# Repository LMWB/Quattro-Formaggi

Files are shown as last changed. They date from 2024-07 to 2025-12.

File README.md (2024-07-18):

# DS18B20_OneWire
One Wire Temperature Sensor Breakout Board on Arduino Shield Format and STM32 Nucleo-F446 Based Software

# Features
- four channels 1-Wire Interface with onboard driver stage 
- designed for DS18B20 Temperature Sensor but any 1-Wire Sensor / Actor would do (minor software adjustments required)
- Industrial ready CAN-Bus interface
    - works with standard (11-Bit) and extended (29-Bit) CAN identifier
- Industrial ready Modbus interface will come soon
- Arduino-Shield layout will fit on several Dev-Boards including all Nucleo-64 boards and Arduino-UNO boards

The 1-Wire Search Algorithm and Driver Stage are basically taken from MAXIM Datasheet and Microship App-Notes.

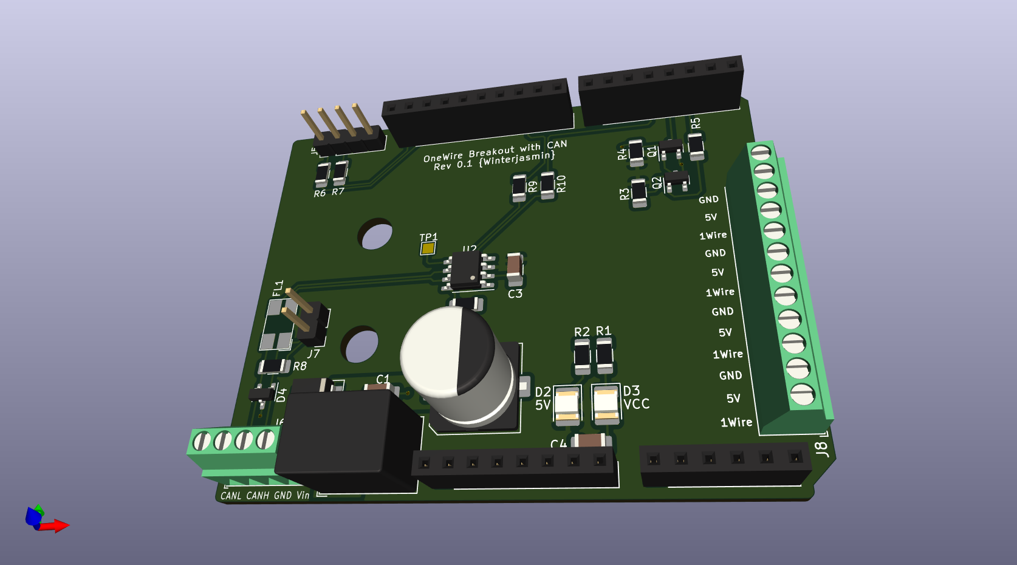
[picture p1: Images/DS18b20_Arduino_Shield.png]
1Wire Arduino Shield

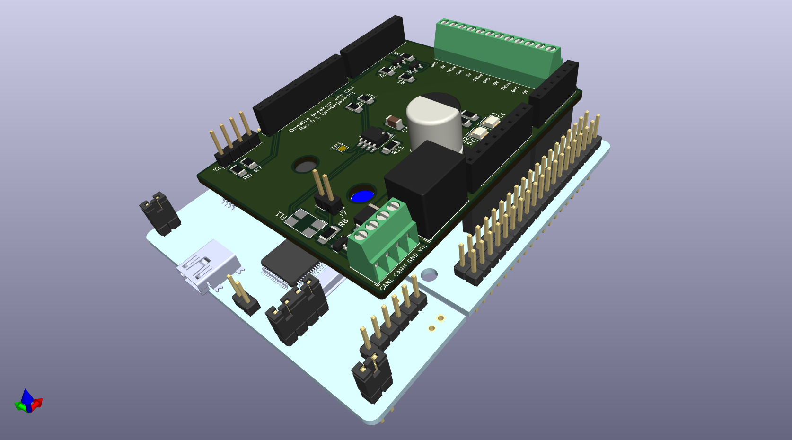
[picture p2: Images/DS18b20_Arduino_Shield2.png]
1Wire Arduino Shield with Nucleo

Schematics

To study some of my testing done so far please have a look [here](/Testing/README.md).

# Quattro Formaggi vs. Quattro Stagioni

# ToDo
- add User-LED on Arduino Shield (Nucleo LED is covered) [HW]
- add Temperature Results to CAN Message [SW]
- use bigger terminal blocks for 1-Wire Interface [HW]
- use bigger terminal blocks for Power Supply and CAN [HW]

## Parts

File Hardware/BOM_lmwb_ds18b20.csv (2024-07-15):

Source: | /home/lukas/KiCad/lmwb_ds18b20/lmwb_ds18b20.kicad_sch
Date: | Sat 03 Feb 2024 16:29:55 CET
Tool: | Eeschema 6.0.11-2627ca5db0~126~ubuntu22.04.1
Generator: | /usr/share/kicad/plugins/bom_csv_grouped_by_value_with_fp.py
Component Count: | 33
Ref | Qnty | Value | Cmp name | Footprint | Description | Vendor
C1, C3, C4, | 3 | 100n | C | Capacitor_SMD:C_1206_3216Metric_Pad1.33x1.80mm_HandSolder | Unpolarized capacitor
C2, | 1 | 47u | C_Polarized | Capacitor_SMD:CP_Elec_10x12.5 | Polarized capacitor
D1, | 1 | US1D | US1D | Diode_SMD:D_SMA | 200V, 1A, General Purpose Rectifier Diode, SMA(DO-214AC)
D2, D3, | 2 | LED_YE | LED | LED_SMD:LED_1210_3225Metric_Pad1.42x2.65mm_HandSolder | Light emitting diode
D4, | 1 | SP0502BAHT | SP0502BAHT | Package_TO_SOT_SMD:SOT-23 | TVS Diode Array, 5.5V Standoff, 2 Channels, SOT-23 package
FL1, | 1 | WE_LineFilter_CAN | WE_LineFilter_CAN | CommonUsedElemetsLMWB:L_CommonModeChoke_CAN_lmwb | EMI 2-inductor filter, pin-connections 1-4 and 2-3
J1, | 1 | Power | Conn_01x08 | Connector_PinSocket_2.54mm:PinSocket_1x08_P2.54mm_Vertical | Generic connector, single row, 01x08, script generated (kicad-library-utils/schlib/autogen/connector/)
J2, | 1 | Digital/PWM | Conn_01x10 | Connector_PinSocket_2.54mm:PinSocket_1x10_P2.54mm_Vertical | Generic connector, single row, 01x10, script generated (kicad-library-utils/schlib/autogen/connector/)
J3, | 1 | Analog | Conn_01x06 | Connector_PinSocket_2.54mm:PinSocket_1x06_P2.54mm_Vertical | Generic connector, single row, 01x06, script generated (kicad-library-utils/schlib/autogen/connector/)
J4, | 1 | Digital/PWM | Conn_01x08 | Connector_PinSocket_2.54mm:PinSocket_1x08_P2.54mm_Vertical | Generic connector, single row, 01x08, script generated (kicad-library-utils/schlib/autogen/connector/)
J5, | 1 | Conn_01x04 | Conn_01x04 | Connector_PinHeader_2.54mm:PinHeader_1x04_P2.54mm_Vertical | Generic connector, single row, 01x04, script generated (kicad-library-utils/schlib/autogen/connector/)
J6, | 1 | Conn_01x04 | Conn_01x04 | TerminalBlock_Phoenix:TerminalBlock_Phoenix_MPT-0,5-4-2.54_1x04_P2.54mm_Horizontal | Generic connector, single row, 01x04, script generated (kicad-library-utils/schlib/autogen/connector/)
J7, | 1 | Conn_01x02_Male | Conn_01x02_Male | Connector_PinHeader_2.54mm:PinHeader_1x02_P2.54mm_Vertical | Generic connector, single row, 01x02, script generated (kicad-library-utils/schlib/autogen/connector/)
J8, | 1 | Conn_01x12 | Conn_01x12 | TerminalBlock_Phoenix:TerminalBlock_Phoenix_MPT-0,5-12-2.54_1x12_P2.54mm_Horizontal | Generic connector, single row, 01x12, script generated (kicad-library-utils/schlib/autogen/connector/)
Q1, Q2, | 2 | BC847 | BC847 | Package_TO_SOT_SMD:SOT-23 | 0.1A Ic, 45V Vce, NPN Transistor, SOT-23
R1, R5, | 2 | 10k | R | Resistor_SMD:R_1206_3216Metric_Pad1.30x1.75mm_HandSolder | Resistor
R2, | 1 | 3k3 | R | Resistor_SMD:R_1206_3216Metric_Pad1.30x1.75mm_HandSolder | Resistor
R3, | 1 | 4k7 | R | Resistor_SMD:R_1206_3216Metric_Pad1.30x1.75mm_HandSolder | Resistor
R4, | 1 | 100k | R | Resistor_SMD:R_1206_3216Metric_Pad1.30x1.75mm_HandSolder | Resistor
R6, R7, | 2 | 47 | R | Resistor_SMD:R_1206_3216Metric_Pad1.30x1.75mm_HandSolder | Resistor
R8, | 1 | 120 | R | Resistor_SMD:R_1206_3216Metric_Pad1.30x1.75mm_HandSolder | Resistor
R9, R10, | 2 | 0 | R | Resistor_SMD:R_1206_3216Metric_Pad1.30x1.75mm_HandSolder | Resistor
R11, | 1 | 22k | R | Resistor_SMD:R_1206_3216Metric_Pad1.30x1.75mm_HandSolder | Resistor
TP1, | 1 | TestPoint_Probe | TestPoint_Probe | TestPoint:TestPoint_Pad_1.5x1.5mm | test point (alternative probe-style design)
U1, | 1 | R-78E9.0-0.5 | R-78E9.0-0.5 | Converter_DCDC:Converter_DCDC_RECOM_R-78E-0.5_THT | 500mA Step-Down DC/DC-Regulator, 12-28V input, 9V fixed Output Voltage, LM78xx replacement, -40°C to +85°C, SIP3
U2, | 1 | MCP2551-I-SN | MCP2551-I-SN | Package_SO:SOIC-8_3.9x4.9mm_P1.27mm | High-Speed CAN Transceiver, 1Mbps, 5V supply, SOIC-8

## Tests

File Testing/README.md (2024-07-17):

# Testing
Because of lacking a proper CAN-Testing-Tool like this [PCAN-USB](https://www.peak-system.com/PCAN-USB.199.0.html?&L=1) I just used a Arduino with CAN-Shield and a minimal Arduino Sketch.
The Arduino program sends periodic test messages and receives CAN-messages from the Nucleo Board. With this I could ensure CAN (especially the CAN transceiver IC) works both directions.

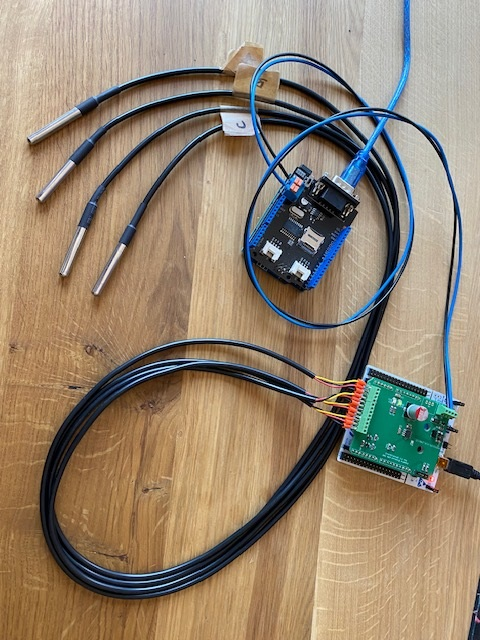
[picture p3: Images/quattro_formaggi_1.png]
arrangement Arduino and Nucleo


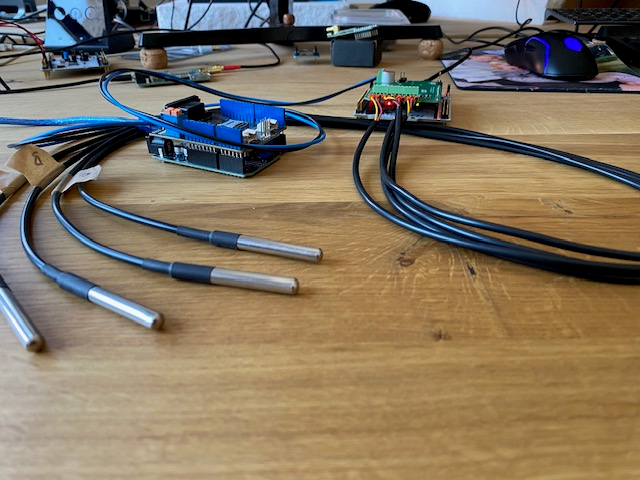
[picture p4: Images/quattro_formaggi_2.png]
arrangement Arduino and Nucleo 2


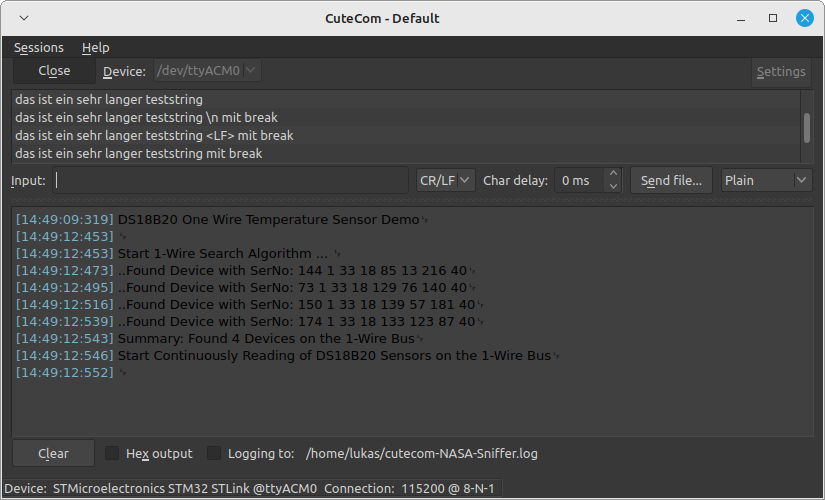
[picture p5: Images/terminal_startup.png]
terminal startup message


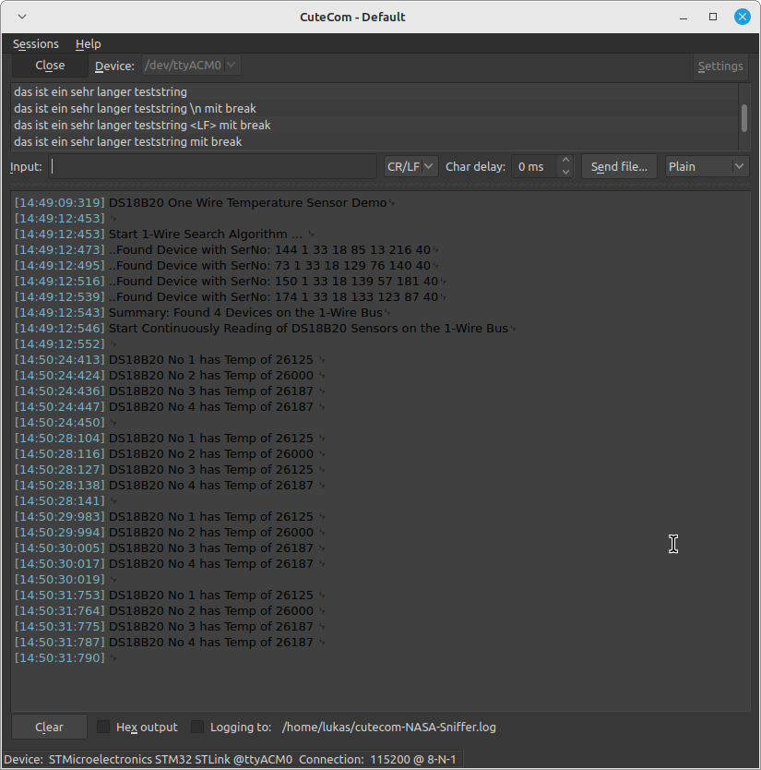
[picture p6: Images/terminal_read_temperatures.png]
terminal search and read DS18B20 sensors


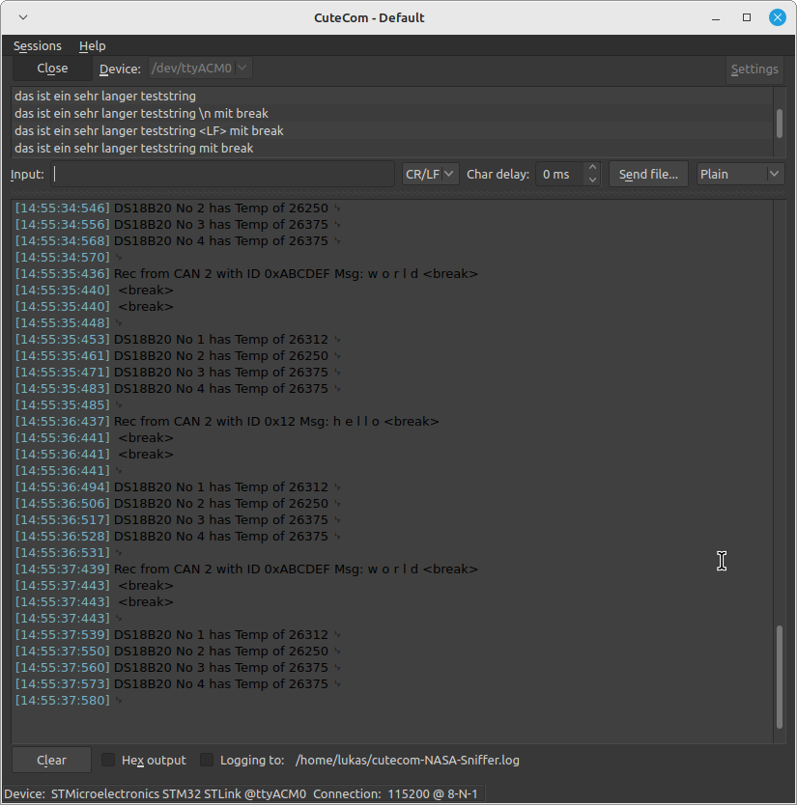
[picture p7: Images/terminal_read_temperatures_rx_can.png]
terminal send and receive CAN messages


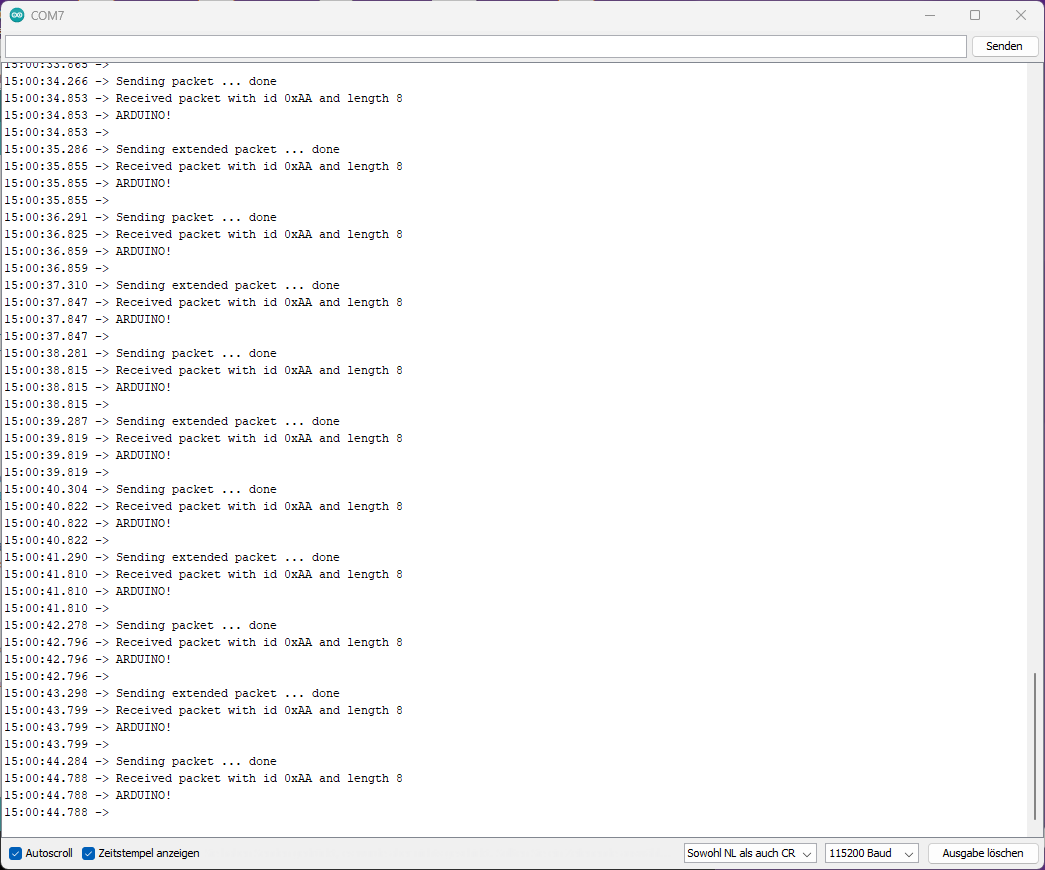
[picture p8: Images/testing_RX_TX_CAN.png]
Arduino terminal send and receive CAN messages


## Hardware
todo

## Software
todo

## CAN-Bus
todo

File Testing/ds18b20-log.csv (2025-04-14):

tick | 5000 | DS18B20_1 | -2500 | GradC | DS18B20_2 | 68000 | GradC | DS18B20_3 | 20875 | GradC | DS18B20_4 | 21062 | GradC
tick | 10000 | DS18B20_1 | -2500 | GradC | DS18B20_2 | 68000 | GradC | DS18B20_3 | 20875 | GradC | DS18B20_4 | 21062 | GradC
tick | 15000 | DS18B20_1 | -2500 | GradC | DS18B20_2 | 67937 | GradC | DS18B20_3 | 20937 | GradC | DS18B20_4 | 21062 | GradC
tick | 20000 | DS18B20_1 | -2500 | GradC | DS18B20_2 | 67875 | GradC | DS18B20_3 | 20875 | GradC | DS18B20_4 | 21062 | GradC
tick | 25000 | DS18B20_1 | -2500 | GradC | DS18B20_2 | 67812 | GradC | DS18B20_3 | 20937 | GradC | DS18B20_4 | 21125 | GradC
tick | 30000 | DS18B20_1 | -2500 | GradC | DS18B20_2 | 67812 | GradC | DS18B20_3 | 20937 | GradC | DS18B20_4 | 21125 | GradC
tick | 35000 | DS18B20_1 | -2500 | GradC | DS18B20_2 | 67750 | GradC | DS18B20_3 | 20937 | GradC | DS18B20_4 | 21125 | GradC
tick | 40000 | DS18B20_1 | -2562 | GradC | DS18B20_2 | 67687 | GradC | DS18B20_3 | 20937 | GradC | DS18B20_4 | 21125 | GradC
tick | 45032 | DS18B20_1 | -2562 | GradC | DS18B20_2 | 67625 | GradC | DS18B20_3 | 20937 | GradC | DS18B20_4 | 21125 | GradC
tick | 50032 | DS18B20_1 | -2562 | GradC | DS18B20_2 | 67625 | GradC | DS18B20_3 | 20937 | GradC | DS18B20_4 | 21125 | GradC
tick | 55032 | DS18B20_1 | -2562 | GradC | DS18B20_2 | 67562 | GradC | DS18B20_3 | 20937 | GradC | DS18B20_4 | 21125 | GradC
tick | 60032 | DS18B20_1 | -2562 | GradC | DS18B20_2 | 67500 | GradC | DS18B20_3 | 20937 | GradC | DS18B20_4 | 21125 | GradC
tick | 65032 | DS18B20_1 | -2562 | GradC | DS18B20_2 | 67437 | GradC | DS18B20_3 | 20937 | GradC | DS18B20_4 | 21125 | GradC
tick | 70032 | DS18B20_1 | -2562 | GradC | DS18B20_2 | 67375 | GradC | DS18B20_3 | 20937 | GradC | DS18B20_4 | 21125 | GradC
tick | 75032 | DS18B20_1 | -2562 | GradC | DS18B20_2 | 67312 | GradC | DS18B20_3 | 20937 | GradC | DS18B20_4 | 21125 | GradC
tick | 80032 | DS18B20_1 | -2562 | GradC | DS18B20_2 | 67250 | GradC | DS18B20_3 | 20937 | GradC | DS18B20_4 | 21125 | GradC
tick | 85032 | DS18B20_1 | -2562 | GradC | DS18B20_2 | 67250 | GradC | DS18B20_3 | 20937 | GradC | DS18B20_4 | 21125 | GradC
tick | 90032 | DS18B20_1 | -2625 | GradC | DS18B20_2 | 67187 | GradC | DS18B20_3 | 20937 | GradC | DS18B20_4 | 21125 | GradC
tick | 95032 | DS18B20_1 | -2625 | GradC | DS18B20_2 | 67062 | GradC | DS18B20_3 | 20937 | GradC | DS18B20_4 | 21187 | GradC
tick | 100032 | DS18B20_1 | -2625 | GradC | DS18B20_2 | 67062 | GradC | DS18B20_3 | 21000 | GradC | DS18B20_4 | 21187 | GradC
tick | 105032 | DS18B20_1 | -2625 | GradC | DS18B20_2 | 67000 | GradC | DS18B20_3 | 21000 | GradC | DS18B20_4 | 21187 | GradC
tick | 110032 | DS18B20_1 | -2625 | GradC | DS18B20_2 | 66937 | GradC | DS18B20_3 | 21000 | GradC | DS18B20_4 | 21187 | GradC
tick | 115032 | DS18B20_1 | -2625 | GradC | DS18B20_2 | 66875 | GradC | DS18B20_3 | 21000 | GradC | DS18B20_4 | 21187 | GradC
tick | 120032 | DS18B20_1 | -2687 | GradC | DS18B20_2 | 66812 | GradC | DS18B20_3 | 21000 | GradC | DS18B20_4 | 21187 | GradC
tick | 125032 | DS18B20_1 | -2687 | GradC | DS18B20_2 | 66750 | GradC | DS18B20_3 | 21000 | GradC | DS18B20_4 | 21187 | GradC
tick | 130032 | DS18B20_1 | -2687 | GradC | DS18B20_2 | 66687 | GradC | DS18B20_3 | 21000 | GradC | DS18B20_4 | 21187 | GradC
tick | 135032 | DS18B20_1 | -2687 | GradC | DS18B20_2 | 66687 | GradC | DS18B20_3 | 21000 | GradC | DS18B20_4 | 21187 | GradC
tick | 140032 | DS18B20_1 | -2687 | GradC | DS18B20_2 | 66562 | GradC | DS18B20_3 | 21000 | GradC | DS18B20_4 | 21187 | GradC
tick | 145032 | DS18B20_1 | -2687 | GradC | DS18B20_2 | 66562 | GradC | DS18B20_3 | 21000 | GradC | DS18B20_4 | 21187 | GradC
tick | 150032 | DS18B20_1 | -2750 | GradC | DS18B20_2 | 66500 | GradC | DS18B20_3 | 21000 | GradC | DS18B20_4 | 21187 | GradC
tick | 155032 | DS18B20_1 | -2750 | GradC | DS18B20_2 | 66437 | GradC | DS18B20_3 | 21000 | GradC | DS18B20_4 | 21187 | GradC
tick | 160044 | DS18B20_1 | -2750 | GradC | DS18B20_2 | 66375 | GradC | DS18B20_3 | 21000 | GradC | DS18B20_4 | 21187 | GradC
tick | 165044 | DS18B20_1 | -2750 | GradC | DS18B20_2 | 66312 | GradC | DS18B20_3 | 21000 | GradC | DS18B20_4 | 21187 | GradC
tick | 170044 | DS18B20_1 | -2750 | GradC | DS18B20_2 | 66250 | GradC | DS18B20_3 | 21000 | GradC | DS18B20_4 | 21187 | GradC
tick | 175044 | DS18B20_1 | -2750 | GradC | DS18B20_2 | 66187 | GradC | DS18B20_3 | 21000 | GradC | DS18B20_4 | 21187 | GradC
tick | 180074 | DS18B20_1 | -2750 | GradC | DS18B20_2 | 66125 | GradC | DS18B20_3 | 21000 | GradC | DS18B20_4 | 21187 | GradC
tick | 185074 | DS18B20_1 | -2812 | GradC | DS18B20_2 | 66125 | GradC | DS18B20_3 | 21000 | GradC | DS18B20_4 | 21187 | GradC
tick | 190074 | DS18B20_1 | -2812 | GradC | DS18B20_2 | 66062 | GradC | DS18B20_3 | 21000 | GradC | DS18B20_4 | 21187 | GradC
tick | 195074 | DS18B20_1 | -2812 | GradC | DS18B20_2 | 66000 | GradC | DS18B20_3 | 21000 | GradC | DS18B20_4 | 21187 | GradC
tick | 200101 | DS18B20_1 | -2812 | GradC | DS18B20_2 | 65937 | GradC | DS18B20_3 | 21000 | GradC | DS18B20_4 | 21187 | GradC
tick | 205101 | DS18B20_1 | -2812 | GradC | DS18B20_2 | 65875 | GradC | DS18B20_3 | 21000 | GradC | DS18B20_4 | 21187 | GradC
tick | 210101 | DS18B20_1 | -2812 | GradC | DS18B20_2 | 65812 | GradC | DS18B20_3 | 21000 | GradC | DS18B20_4 | 21187 | GradC
tick | 215101 | DS18B20_1 | -2812 | GradC | DS18B20_2 | 65687 | GradC | DS18B20_3 | 21000 | GradC | DS18B20_4 | 21187 | GradC
tick | 220127 | DS18B20_1 | -2875 | GradC | DS18B20_2 | 65625 | GradC | DS18B20_3 | 21000 | GradC | DS18B20_4 | 21187 | GradC
tick | 225127 | DS18B20_1 | -2875 | GradC | DS18B20_2 | 65625 | GradC | DS18B20_3 | 21000 | GradC | DS18B20_4 | 21187 | GradC
tick | 230127 | DS18B20_1 | -2875 | GradC | DS18B20_2 | 65562 | GradC | DS18B20_3 | 21000 | GradC | DS18B20_4 | 21187 | GradC
tick | 235127 | DS18B20_1 | -2875 | GradC | DS18B20_2 | 65500 | GradC | DS18B20_3 | 21000 | GradC | DS18B20_4 | 21187 | GradC
tick | 240156 | DS18B20_1 | -2875 | GradC | DS18B20_2 | 65437 | GradC | DS18B20_3 | 21000 | GradC | DS18B20_4 | 21187 | GradC
tick | 245156 | DS18B20_1 | -2875 | GradC | DS18B20_2 | 65375 | GradC | DS18B20_3 | 21000 | GradC | DS18B20_4 | 21250 | GradC
tick | 250156 | DS18B20_1 | -2875 | GradC | DS18B20_2 | 65312 | GradC | DS18B20_3 | 21000 | GradC | DS18B20_4 | 21187 | GradC
tick | 255156 | DS18B20_1 | -2875 | GradC | DS18B20_2 | 65250 | GradC | DS18B20_3 | 21000 | GradC | DS18B20_4 | 21187 | GradC
tick | 260188 | DS18B20_1 | -2937 | GradC | DS18B20_2 | 65187 | GradC | DS18B20_3 | 21000 | GradC | DS18B20_4 | 21250 | GradC
tick | 265188 | DS18B20_1 | -2937 | GradC | DS18B20_2 | 65125 | GradC | DS18B20_3 | 21000 | GradC | DS18B20_4 | 21187 | GradC
tick | 270188 | DS18B20_1 | -2937 | GradC | DS18B20_2 | 65062 | GradC | DS18B20_3 | 21000 | GradC | DS18B20_4 | 21187 | GradC
tick | 275188 | DS18B20_1 | -2937 | GradC | DS18B20_2 | 65000 | GradC | DS18B20_3 | 21000 | GradC | DS18B20_4 | 21250 | GradC
tick | 280222 | DS18B20_1 | -2937 | GradC | DS18B20_2 | 64937 | GradC | DS18B20_3 | 21000 | GradC | DS18B20_4 | 21187 | GradC
tick | 285222 | DS18B20_1 | -2937 | GradC | DS18B20_2 | 64875 | GradC | DS18B20_3 | 21000 | GradC | DS18B20_4 | 21187 | GradC
tick | 290222 | DS18B20_1 | -2937 | GradC | DS18B20_2 | 64812 | GradC | DS18B20_3 | 21000 | GradC | DS18B20_4 | 21187 | GradC
tick | 295222 | DS18B20_1 | -2937 | GradC | DS18B20_2 | 64750 | GradC | DS18B20_3 | 21000 | GradC | DS18B20_4 | 21250 | GradC
tick | 300257 | DS18B20_1 | -3000 | GradC | DS18B20_2 | 64687 | GradC | DS18B20_3 | 21000 | GradC | DS18B20_4 | 21250 | GradC
tick | 305257 | DS18B20_1 | -3000 | GradC | DS18B20_2 | 64625 | GradC | DS18B20_3 | 21000 | GradC | DS18B20_4 | 21250 | GradC
tick | 310257 | DS18B20_1 | -3000 | GradC | DS18B20_2 | 64562 | GradC | DS18B20_3 | 21000 | GradC | DS18B20_4 | 21187 | GradC
tick | 315257 | DS18B20_1 | -3000 | GradC | DS18B20_2 | 64500 | GradC | DS18B20_3 | 21062 | GradC | DS18B20_4 | 21250 | GradC
tick | 320290 | DS18B20_1 | -3000 | GradC | DS18B20_2 | 64437 | GradC | DS18B20_3 | 21000 | GradC | DS18B20_4 | 21187 | GradC
tick | 325290 | DS18B20_1 | -3000 | GradC | DS18B20_2 | 64437 | GradC | DS18B20_3 | 21000 | GradC | DS18B20_4 | 21250 | GradC
tick | 330290 | DS18B20_1 | -3000 | GradC | DS18B20_2 | 64375 | GradC | DS18B20_3 | 21000 | GradC | DS18B20_4 | 21250 | GradC
tick | 335290 | DS18B20_1 | -3062 | GradC | DS18B20_2 | 64312 | GradC | DS18B20_3 | 21000 | GradC | DS18B20_4 | 21250 | GradC
tick | 340320 | DS18B20_1 | -3062 | GradC | DS18B20_2 | 64250 | GradC | DS18B20_3 | 21000 | GradC | DS18B20_4 | 21250 | GradC
tick | 345320 | DS18B20_1 | -3062 | GradC | DS18B20_2 | 64187 | GradC | DS18B20_3 | 21000 | GradC | DS18B20_4 | 21250 | GradC
tick | 350320 | DS18B20_1 | -3062 | GradC | DS18B20_2 | 64125 | GradC | DS18B20_3 | 21000 | GradC | DS18B20_4 | 21250 | GradC
tick | 355320 | DS18B20_1 | -3062 | GradC | DS18B20_2 | 64062 | GradC | DS18B20_3 | 21000 | GradC | DS18B20_4 | 21250 | GradC
tick | 360349 | DS18B20_1 | -3062 | GradC | DS18B20_2 | 64000 | GradC | DS18B20_3 | 21000 | GradC | DS18B20_4 | 21187 | GradC
tick | 365349 | DS18B20_1 | -3062 | GradC | DS18B20_2 | 63937 | GradC | DS18B20_3 | 21000 | GradC | DS18B20_4 | 21187 | GradC
tick | 370349 | DS18B20_1 | -3062 | GradC | DS18B20_2 | 63937 | GradC | DS18B20_3 | 21000 | GradC | DS18B20_4 | 21250 | GradC
tick | 375349 | DS18B20_1 | -3062 | GradC | DS18B20_2 | 63875 | GradC | DS18B20_3 | 21000 | GradC | DS18B20_4 | 21250 | GradC
tick | 380379 | DS18B20_1 | -3125 | GradC | DS18B20_2 | 63812 | GradC | DS18B20_3 | 21000 | GradC | DS18B20_4 | 21250 | GradC
tick | 385379 | DS18B20_1 | -3125 | GradC | DS18B20_2 | 63750 | GradC | DS18B20_3 | 21000 | GradC | DS18B20_4 | 21250 | GradC
tick | 390379 | DS18B20_1 | -3125 | GradC | DS18B20_2 | 63687 | GradC | DS18B20_3 | 21000 | GradC | DS18B20_4 | 21250 | GradC
tick | 395379 | DS18B20_1 | -3125 | GradC | DS18B20_2 | 63625 | GradC | DS18B20_3 | 21000 | GradC | DS18B20_4 | 21250 | GradC
tick | 400411 | DS18B20_1 | -3125 | GradC | DS18B20_2 | 63562 | GradC | DS18B20_3 | 21000 | GradC | DS18B20_4 | 21187 | GradC
tick | 405411 | DS18B20_1 | -3125 | GradC | DS18B20_2 | 63500 | GradC | DS18B20_3 | 21000 | GradC | DS18B20_4 | 21187 | GradC
tick | 410411 | DS18B20_1 | -3125 | GradC | DS18B20_2 | 63437 | GradC | DS18B20_3 | 21000 | GradC | DS18B20_4 | 21250 | GradC
tick | 415411 | DS18B20_1 | -3125 | GradC | DS18B20_2 | 63437 | GradC | DS18B20_3 | 21000 | GradC | DS18B20_4 | 21187 | GradC
tick | 420440 | DS18B20_1 | -3187 | GradC | DS18B20_2 | 63375 | GradC | DS18B20_3 | 21000 | GradC | DS18B20_4 | 21187 | GradC
tick | 425440 | DS18B20_1 | -3187 | GradC | DS18B20_2 | 63312 | GradC | DS18B20_3 | 21000 | GradC | DS18B20_4 | 21187 | GradC
tick | 430440 | DS18B20_1 | -3187 | GradC | DS18B20_2 | 63250 | GradC | DS18B20_3 | 21000 | GradC | DS18B20_4 | 21250 | GradC
tick | 435440 | DS18B20_1 | -3187 | GradC | DS18B20_2 | 63187 | GradC | DS18B20_3 | 21000 | GradC | DS18B20_4 | 21187 | GradC
tick | 440461 | DS18B20_1 | -3187 | GradC | DS18B20_2 | 63125 | GradC | DS18B20_3 | 21000 | GradC | DS18B20_4 | 21187 | GradC
tick | 445461 | DS18B20_1 | -3187 | GradC | DS18B20_2 | 63062 | GradC | DS18B20_3 | 21000 | GradC | DS18B20_4 | 21187 | GradC
tick | 450461 | DS18B20_1 | -3187 | GradC | DS18B20_2 | 63000 | GradC | DS18B20_3 | 21000 | GradC | DS18B20_4 | 21187 | GradC
tick | 455461 | DS18B20_1 | -3187 | GradC | DS18B20_2 | 62937 | GradC | DS18B20_3 | 21000 | GradC | DS18B20_4 | 21187 | GradC
tick | 460475 | DS18B20_1 | -3250 | GradC | DS18B20_2 | 62875 | GradC | DS18B20_3 | 21000 | GradC | DS18B20_4 | 21187 | GradC
tick | 465475 | DS18B20_1 | -3250 | GradC | DS18B20_2 | 62812 | GradC | DS18B20_3 | 21000 | GradC | DS18B20_4 | 21187 | GradC
tick | 470475 | DS18B20_1 | -3250 | GradC | DS18B20_2 | 62750 | GradC | DS18B20_3 | 21000 | GradC | DS18B20_4 | 21187 | GradC
tick | 475475 | DS18B20_1 | -3250 | GradC | DS18B20_2 | 62687 | GradC | DS18B20_3 | 21000 | GradC | DS18B20_4 | 21187 | GradC
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

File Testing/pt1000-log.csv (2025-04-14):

tick | 5000 | PT1000_1 | 983 | Ohm | -4426 | GradC | PT1000_2 | 1269 | Ohm | 69533 | GradC | PT1000_3 | 1084 | Ohm | 21692 | GradC | PT1000_4 | 1081 | Ohm | 20916 | GradCCPU_Temperature | 31 | GradC
tick | 10000 | PT1000_1 | 983 | Ohm | -4426 | GradC | PT1000_2 | 1269 | Ohm | 69533 | GradC | PT1000_3 | 1083 | Ohm | 21433 | GradC | PT1000_4 | 1081 | Ohm | 20916 | GradCCPU_Temperature | 31 | GradC
tick | 15000 | PT1000_1 | 983 | Ohm | -4426 | GradC | PT1000_2 | 1268 | Ohm | 69274 | GradC | PT1000_3 | 1083 | Ohm | 21433 | GradC | PT1000_4 | 1081 | Ohm | 20916 | GradCCPU_Temperature | 31 | GradC
tick | 20000 | PT1000_1 | 983 | Ohm | -4426 | GradC | PT1000_2 | 1268 | Ohm | 69274 | GradC | PT1000_3 | 1083 | Ohm | 21433 | GradC | PT1000_4 | 1081 | Ohm | 20916 | GradCCPU_Temperature | 31 | GradC
tick | 25000 | PT1000_1 | 983 | Ohm | -4426 | GradC | PT1000_2 | 1268 | Ohm | 69274 | GradC | PT1000_3 | 1083 | Ohm | 21433 | GradC | PT1000_4 | 1081 | Ohm | 20916 | GradCCPU_Temperature | 31 | GradC
tick | 30000 | PT1000_1 | 983 | Ohm | -4426 | GradC | PT1000_2 | 1268 | Ohm | 69274 | GradC | PT1000_3 | 1083 | Ohm | 21433 | GradC | PT1000_4 | 1081 | Ohm | 20916 | GradCCPU_Temperature | 31 | GradC
tick | 35000 | PT1000_1 | 982 | Ohm | -4684 | GradC | PT1000_2 | 1268 | Ohm | 69274 | GradC | PT1000_3 | 1083 | Ohm | 21433 | GradC | PT1000_4 | 1081 | Ohm | 20916 | GradCCPU_Temperature | 31 | GradC
tick | 40000 | PT1000_1 | 982 | Ohm | -4684 | GradC | PT1000_2 | 1268 | Ohm | 69274 | GradC | PT1000_3 | 1083 | Ohm | 21433 | GradC | PT1000_4 | 1081 | Ohm | 20916 | GradCCPU_Temperature | 31 | GradC
tick | 45000 | PT1000_1 | 983 | Ohm | -4426 | GradC | PT1000_2 | 1267 | Ohm | 69016 | GradC | PT1000_3 | 1084 | Ohm | 21692 | GradC | PT1000_4 | 1081 | Ohm | 20916 | GradCCPU_Temperature | 31 | GradC
tick | 50000 | PT1000_1 | 983 | Ohm | -4426 | GradC | PT1000_2 | 1265 | Ohm | 68499 | GradC | PT1000_3 | 1083 | Ohm | 21433 | GradC | PT1000_4 | 1081 | Ohm | 20916 | GradCCPU_Temperature | 31 | GradC
tick | 55000 | PT1000_1 | 982 | Ohm | -4684 | GradC | PT1000_2 | 1266 | Ohm | 68757 | GradC | PT1000_3 | 1083 | Ohm | 21433 | GradC | PT1000_4 | 1081 | Ohm | 20916 | GradCCPU_Temperature | 30 | GradC
tick | 60000 | PT1000_1 | 982 | Ohm | -4684 | GradC | PT1000_2 | 1267 | Ohm | 69016 | GradC | PT1000_3 | 1083 | Ohm | 21433 | GradC | PT1000_4 | 1081 | Ohm | 20916 | GradCCPU_Temperature | 31 | GradC
tick | 65000 | PT1000_1 | 983 | Ohm | -4426 | GradC | PT1000_2 | 1267 | Ohm | 69016 | GradC | PT1000_3 | 1083 | Ohm | 21433 | GradC | PT1000_4 | 1081 | Ohm | 20916 | GradCCPU_Temperature | 31 | GradC
tick | 70000 | PT1000_1 | 983 | Ohm | -4426 | GradC | PT1000_2 | 1266 | Ohm | 68757 | GradC | PT1000_3 | 1083 | Ohm | 21433 | GradC | PT1000_4 | 1081 | Ohm | 20916 | GradCCPU_Temperature | 31 | GradC
tick | 75000 | PT1000_1 | 983 | Ohm | -4426 | GradC | PT1000_2 | 1266 | Ohm | 68757 | GradC | PT1000_3 | 1083 | Ohm | 21433 | GradC | PT1000_4 | 1081 | Ohm | 20916 | GradCCPU_Temperature | 31 | GradC
tick | 80000 | PT1000_1 | 982 | Ohm | -4684 | GradC | PT1000_2 | 1265 | Ohm | 68499 | GradC | PT1000_3 | 1084 | Ohm | 21692 | GradC | PT1000_4 | 1082 | Ohm | 21175 | GradCCPU_Temperature | 31 | GradC
tick | 85000 | PT1000_1 | 983 | Ohm | -4426 | GradC | PT1000_2 | 1266 | Ohm | 68757 | GradC | PT1000_3 | 1083 | Ohm | 21433 | GradC | PT1000_4 | 1081 | Ohm | 20916 | GradCCPU_Temperature | 31 | GradC
tick | 90000 | PT1000_1 | 982 | Ohm | -4684 | GradC | PT1000_2 | 1265 | Ohm | 68499 | GradC | PT1000_3 | 1084 | Ohm | 21692 | GradC | PT1000_4 | 1081 | Ohm | 20916 | GradCCPU_Temperature | 31 | GradC
tick | 95000 | PT1000_1 | 982 | Ohm | -4684 | GradC | PT1000_2 | 1265 | Ohm | 68499 | GradC | PT1000_3 | 1083 | Ohm | 21433 | GradC | PT1000_4 | 1081 | Ohm | 20916 | GradCCPU_Temperature | 31 | GradC
tick | 100000 | PT1000_1 | 982 | Ohm | -4684 | GradC | PT1000_2 | 1265 | Ohm | 68499 | GradC | PT1000_3 | 1083 | Ohm | 21433 | GradC | PT1000_4 | 1081 | Ohm | 20916 | GradCCPU_Temperature | 31 | GradC
tick | 105000 | PT1000_1 | 982 | Ohm | -4684 | GradC | PT1000_2 | 1265 | Ohm | 68499 | GradC | PT1000_3 | 1083 | Ohm | 21433 | GradC | PT1000_4 | 1081 | Ohm | 20916 | GradCCPU_Temperature | 31 | GradC
tick | 110000 | PT1000_1 | 982 | Ohm | -4684 | GradC | PT1000_2 | 1264 | Ohm | 68240 | GradC | PT1000_3 | 1083 | Ohm | 21433 | GradC | PT1000_4 | 1081 | Ohm | 20916 | GradCCPU_Temperature | 31 | GradC
tick | 115000 | PT1000_1 | 982 | Ohm | -4684 | GradC | PT1000_2 | 1264 | Ohm | 68240 | GradC | PT1000_3 | 1083 | Ohm | 21433 | GradC | PT1000_4 | 1082 | Ohm | 21175 | GradCCPU_Temperature | 30 | GradC
tick | 120000 | PT1000_1 | 982 | Ohm | -4684 | GradC | PT1000_2 | 1264 | Ohm | 68240 | GradC | PT1000_3 | 1083 | Ohm | 21433 | GradC | PT1000_4 | 1081 | Ohm | 20916 | GradCCPU_Temperature | 31 | GradC
tick | 125000 | PT1000_1 | 982 | Ohm | -4684 | GradC | PT1000_2 | 1264 | Ohm | 68240 | GradC | PT1000_3 | 1083 | Ohm | 21433 | GradC | PT1000_4 | 1081 | Ohm | 20916 | GradCCPU_Temperature | 31 | GradC
tick | 130000 | PT1000_1 | 981 | Ohm | -4943 | GradC | PT1000_2 | 1263 | Ohm | 67981 | GradC | PT1000_3 | 1083 | Ohm | 21433 | GradC | PT1000_4 | 1081 | Ohm | 20916 | GradCCPU_Temperature | 31 | GradC
tick | 135000 | PT1000_1 | 982 | Ohm | -4684 | GradC | PT1000_2 | 1263 | Ohm | 67981 | GradC | PT1000_3 | 1084 | Ohm | 21692 | GradC | PT1000_4 | 1081 | Ohm | 20916 | GradCCPU_Temperature | 31 | GradC
tick | 140000 | PT1000_1 | 982 | Ohm | -4684 | GradC | PT1000_2 | 1263 | Ohm | 67981 | GradC | PT1000_3 | 1083 | Ohm | 21433 | GradC | PT1000_4 | 1081 | Ohm | 20916 | GradCCPU_Temperature | 31 | GradC
tick | 145000 | PT1000_1 | 982 | Ohm | -4684 | GradC | PT1000_2 | 1261 | Ohm | 67464 | GradC | PT1000_3 | 1083 | Ohm | 21433 | GradC | PT1000_4 | 1081 | Ohm | 20916 | GradCCPU_Temperature | 31 | GradC
tick | 150000 | PT1000_1 | 982 | Ohm | -4684 | GradC | PT1000_2 | 1263 | Ohm | 67981 | GradC | PT1000_3 | 1083 | Ohm | 21433 | GradC | PT1000_4 | 1081 | Ohm | 20916 | GradCCPU_Temperature | 31 | GradC
tick | 155000 | PT1000_1 | 982 | Ohm | -4684 | GradC | PT1000_2 | 1262 | Ohm | 67723 | GradC | PT1000_3 | 1083 | Ohm | 21433 | GradC | PT1000_4 | 1081 | Ohm | 20916 | GradCCPU_Temperature | 31 | GradC
tick | 160000 | PT1000_1 | 982 | Ohm | -4684 | GradC | PT1000_2 | 1262 | Ohm | 67723 | GradC | PT1000_3 | 1082 | Ohm | 21175 | GradC | PT1000_4 | 1081 | Ohm | 20916 | GradCCPU_Temperature | 31 | GradC
tick | 165000 | PT1000_1 | 981 | Ohm | -4943 | GradC | PT1000_2 | 1262 | Ohm | 67723 | GradC | PT1000_3 | 1083 | Ohm | 21433 | GradC | PT1000_4 | 1082 | Ohm | 21175 | GradCCPU_Temperature | 30 | GradC
tick | 170000 | PT1000_1 | 982 | Ohm | -4684 | GradC | PT1000_2 | 1262 | Ohm | 67723 | GradC | PT1000_3 | 1083 | Ohm | 21433 | GradC | PT1000_4 | 1081 | Ohm | 20916 | GradCCPU_Temperature | 31 | GradC
tick | 175000 | PT1000_1 | 981 | Ohm | -4943 | GradC | PT1000_2 | 1261 | Ohm | 67464 | GradC | PT1000_3 | 1083 | Ohm | 21433 | GradC | PT1000_4 | 1082 | Ohm | 21175 | GradCCPU_Temperature | 31 | GradC
tick | 180000 | PT1000_1 | 982 | Ohm | -4684 | GradC | PT1000_2 | 1262 | Ohm | 67723 | GradC | PT1000_3 | 1083 | Ohm | 21433 | GradC | PT1000_4 | 1081 | Ohm | 20916 | GradCCPU_Temperature | 31 | GradC
tick | 185000 | PT1000_1 | 982 | Ohm | -4684 | GradC | PT1000_2 | 1261 | Ohm | 67464 | GradC | PT1000_3 | 1083 | Ohm | 21433 | GradC | PT1000_4 | 1081 | Ohm | 20916 | GradCCPU_Temperature | 31 | GradC
tick | 190000 | PT1000_1 | 981 | Ohm | -4943 | GradC | PT1000_2 | 1260 | Ohm | 67206 | GradC | PT1000_3 | 1083 | Ohm | 21433 | GradC | PT1000_4 | 1081 | Ohm | 20916 | GradCCPU_Temperature | 31 | GradC
tick | 195000 | PT1000_1 | 981 | Ohm | -4943 | GradC | PT1000_2 | 1261 | Ohm | 67464 | GradC | PT1000_3 | 1083 | Ohm | 21433 | GradC | PT1000_4 | 1081 | Ohm | 20916 | GradCCPU_Temperature | 31 | GradC
tick | 200000 | PT1000_1 | 982 | Ohm | -4684 | GradC | PT1000_2 | 1260 | Ohm | 67206 | GradC | PT1000_3 | 1083 | Ohm | 21433 | GradC | PT1000_4 | 1081 | Ohm | 20916 | GradCCPU_Temperature | 31 | GradC
tick | 205000 | PT1000_1 | 982 | Ohm | -4684 | GradC | PT1000_2 | 1260 | Ohm | 67206 | GradC | PT1000_3 | 1083 | Ohm | 21433 | GradC | PT1000_4 | 1081 | Ohm | 20916 | GradCCPU_Temperature | 31 | GradC
tick | 210000 | PT1000_1 | 981 | Ohm | -4943 | GradC | PT1000_2 | 1260 | Ohm | 67206 | GradC | PT1000_3 | 1082 | Ohm | 21175 | GradC | PT1000_4 | 1081 | Ohm | 20916 | GradCCPU_Temperature | 31 | GradC
tick | 215000 | PT1000_1 | 982 | Ohm | -4684 | GradC | PT1000_2 | 1261 | Ohm | 67464 | GradC | PT1000_3 | 1083 | Ohm | 21433 | GradC | PT1000_4 | 1081 | Ohm | 20916 | GradCCPU_Temperature | 31 | GradC
tick | 220000 | PT1000_1 | 982 | Ohm | -4684 | GradC | PT1000_2 | 1260 | Ohm | 67206 | GradC | PT1000_3 | 1083 | Ohm | 21433 | GradC | PT1000_4 | 1081 | Ohm | 20916 | GradCCPU_Temperature | 31 | GradC
tick | 225000 | PT1000_1 | 981 | Ohm | -4943 | GradC | PT1000_2 | 1257 | Ohm | 66430 | GradC | PT1000_3 | 1083 | Ohm | 21433 | GradC | PT1000_4 | 1081 | Ohm | 20916 | GradCCPU_Temperature | 31 | GradC
tick | 230000 | PT1000_1 | 981 | Ohm | -4943 | GradC | PT1000_2 | 1259 | Ohm | 66947 | GradC | PT1000_3 | 1083 | Ohm | 21433 | GradC | PT1000_4 | 1081 | Ohm | 20916 | GradCCPU_Temperature | 31 | GradC
tick | 235000 | PT1000_1 | 982 | Ohm | -4684 | GradC | PT1000_2 | 1257 | Ohm | 66430 | GradC | PT1000_3 | 1083 | Ohm | 21433 | GradC | PT1000_4 | 1081 | Ohm | 20916 | GradCCPU_Temperature | 31 | GradC
tick | 240000 | PT1000_1 | 980 | Ohm | -5202 | GradC | PT1000_2 | 1258 | Ohm | 66688 | GradC | PT1000_3 | 1083 | Ohm | 21433 | GradC | PT1000_4 | 1081 | Ohm | 20916 | GradCCPU_Temperature | 31 | GradC
tick | 245000 | PT1000_1 | 982 | Ohm | -4684 | GradC | PT1000_2 | 1256 | Ohm | 66171 | GradC | PT1000_3 | 1083 | Ohm | 21433 | GradC | PT1000_4 | 1082 | Ohm | 21175 | GradCCPU_Temperature | 31 | GradC
tick | 250000 | PT1000_1 | 982 | Ohm | -4684 | GradC | PT1000_2 | 1258 | Ohm | 66688 | GradC | PT1000_3 | 1083 | Ohm | 21433 | GradC | PT1000_4 | 1081 | Ohm | 20916 | GradCCPU_Temperature | 31 | GradC
tick | 255000 | PT1000_1 | 981 | Ohm | -4943 | GradC | PT1000_2 | 1259 | Ohm | 66947 | GradC | PT1000_3 | 1083 | Ohm | 21433 | GradC | PT1000_4 | 1081 | Ohm | 20916 | GradCCPU_Temperature | 31 | GradC
tick | 260000 | PT1000_1 | 981 | Ohm | -4943 | GradC | PT1000_2 | 1257 | Ohm | 66430 | GradC | PT1000_3 | 1082 | Ohm | 21175 | GradC | PT1000_4 | 1081 | Ohm | 20916 | GradCCPU_Temperature | 31 | GradC
tick | 265000 | PT1000_1 | 981 | Ohm | -4943 | GradC | PT1000_2 | 1257 | Ohm | 66430 | GradC | PT1000_3 | 1083 | Ohm | 21433 | GradC | PT1000_4 | 1081 | Ohm | 20916 | GradCCPU_Temperature | 31 | GradC
tick | 270000 | PT1000_1 | 982 | Ohm | -4684 | GradC | PT1000_2 | 1258 | Ohm | 66688 | GradC | PT1000_3 | 1083 | Ohm | 21433 | GradC | PT1000_4 | 1082 | Ohm | 21175 | GradCCPU_Temperature | 31 | GradC
tick | 275000 | PT1000_1 | 981 | Ohm | -4943 | GradC | PT1000_2 | 1257 | Ohm | 66430 | GradC | PT1000_3 | 1083 | Ohm | 21433 | GradC | PT1000_4 | 1081 | Ohm | 20916 | GradCCPU_Temperature | 31 | GradC
tick | 280000 | PT1000_1 | 981 | Ohm | -4943 | GradC | PT1000_2 | 1257 | Ohm | 66430 | GradC | PT1000_3 | 1083 | Ohm | 21433 | GradC | PT1000_4 | 1081 | Ohm | 20916 | GradCCPU_Temperature | 31 | GradC
tick | 285000 | PT1000_1 | 981 | Ohm | -4943 | GradC | PT1000_2 | 1256 | Ohm | 66171 | GradC | PT1000_3 | 1083 | Ohm | 21433 | GradC | PT1000_4 | 1081 | Ohm | 20916 | GradCCPU_Temperature | 31 | GradC
tick | 290000 | PT1000_1 | 981 | Ohm | -4943 | GradC | PT1000_2 | 1257 | Ohm | 66430 | GradC | PT1000_3 | 1084 | Ohm | 21692 | GradC | PT1000_4 | 1081 | Ohm | 20916 | GradCCPU_Temperature | 31 | GradC
tick | 295000 | PT1000_1 | 981 | Ohm | -4943 | GradC | PT1000_2 | 1253 | Ohm | 65395 | GradC | PT1000_3 | 1084 | Ohm | 21692 | GradC | PT1000_4 | 1081 | Ohm | 20916 | GradCCPU_Temperature | 31 | GradC
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

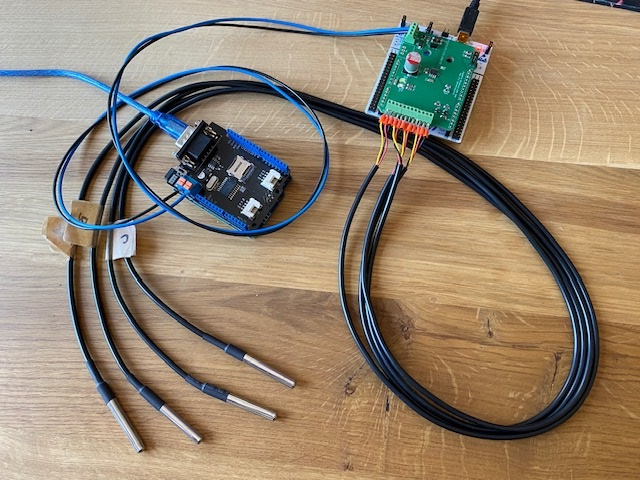
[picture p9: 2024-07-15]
Testing/quattro_formaggi_1.png

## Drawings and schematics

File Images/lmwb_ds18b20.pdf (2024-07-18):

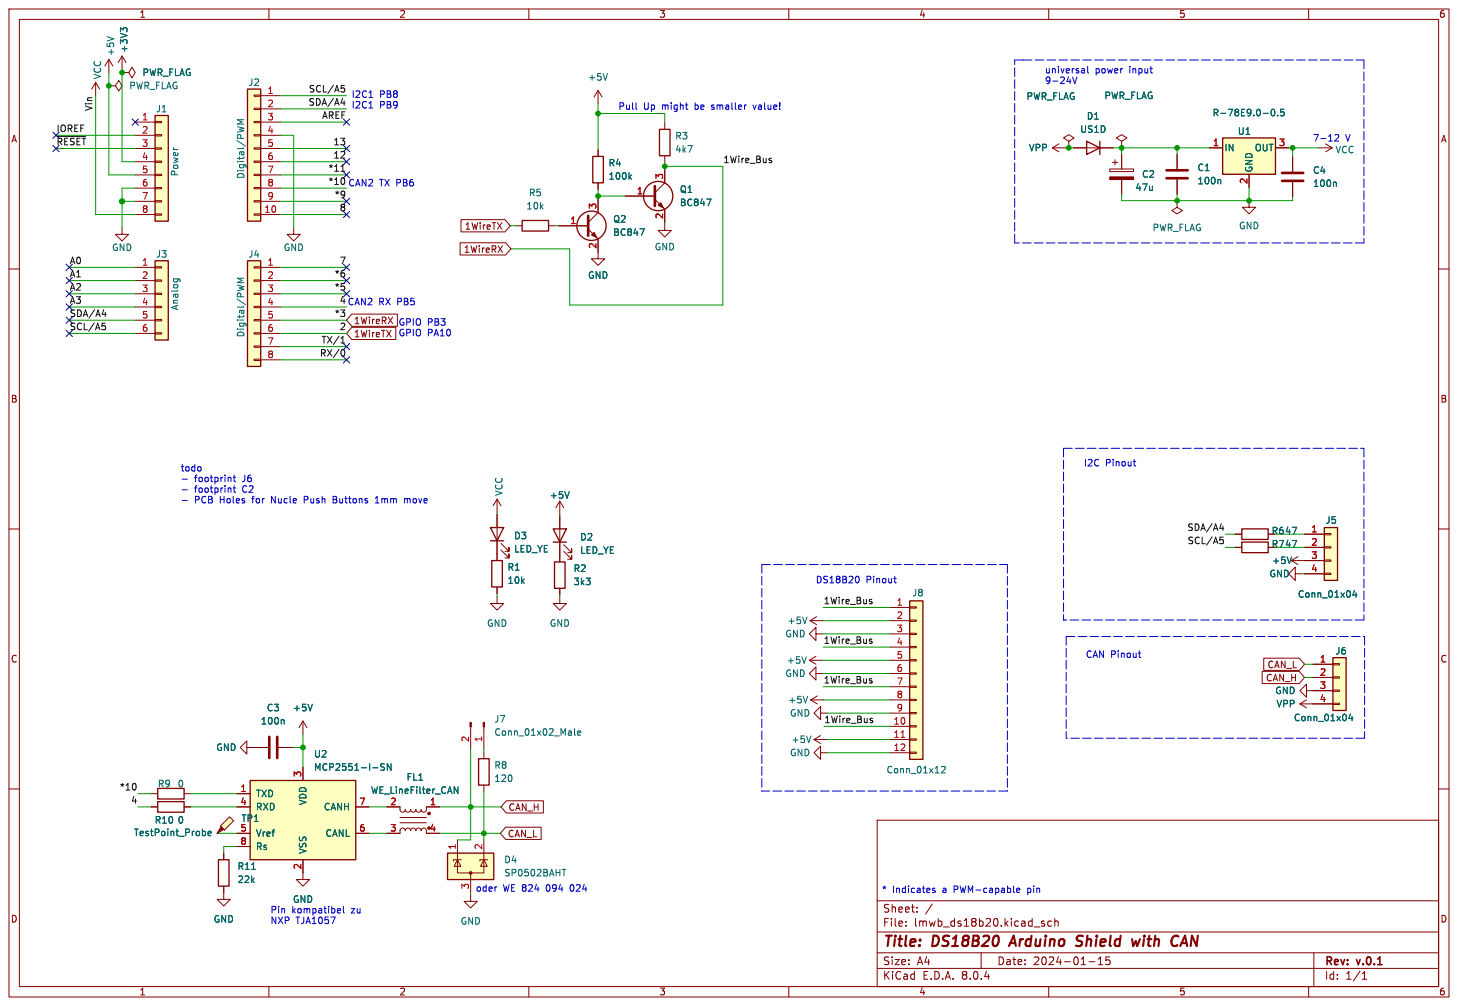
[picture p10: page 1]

todo
- PCB Holes for Nucle Push Buttons 1mm move

3 RXD 4 Vref 5 CANL 6 CANH 7 Rs 8 U2 MCP2551-I-SN

3 RXD 4 Vref 5 CANL 6 CANH 7 Rs 8R11

Id: 1/1 Title: DS18B20 Arduino Shield with CAN

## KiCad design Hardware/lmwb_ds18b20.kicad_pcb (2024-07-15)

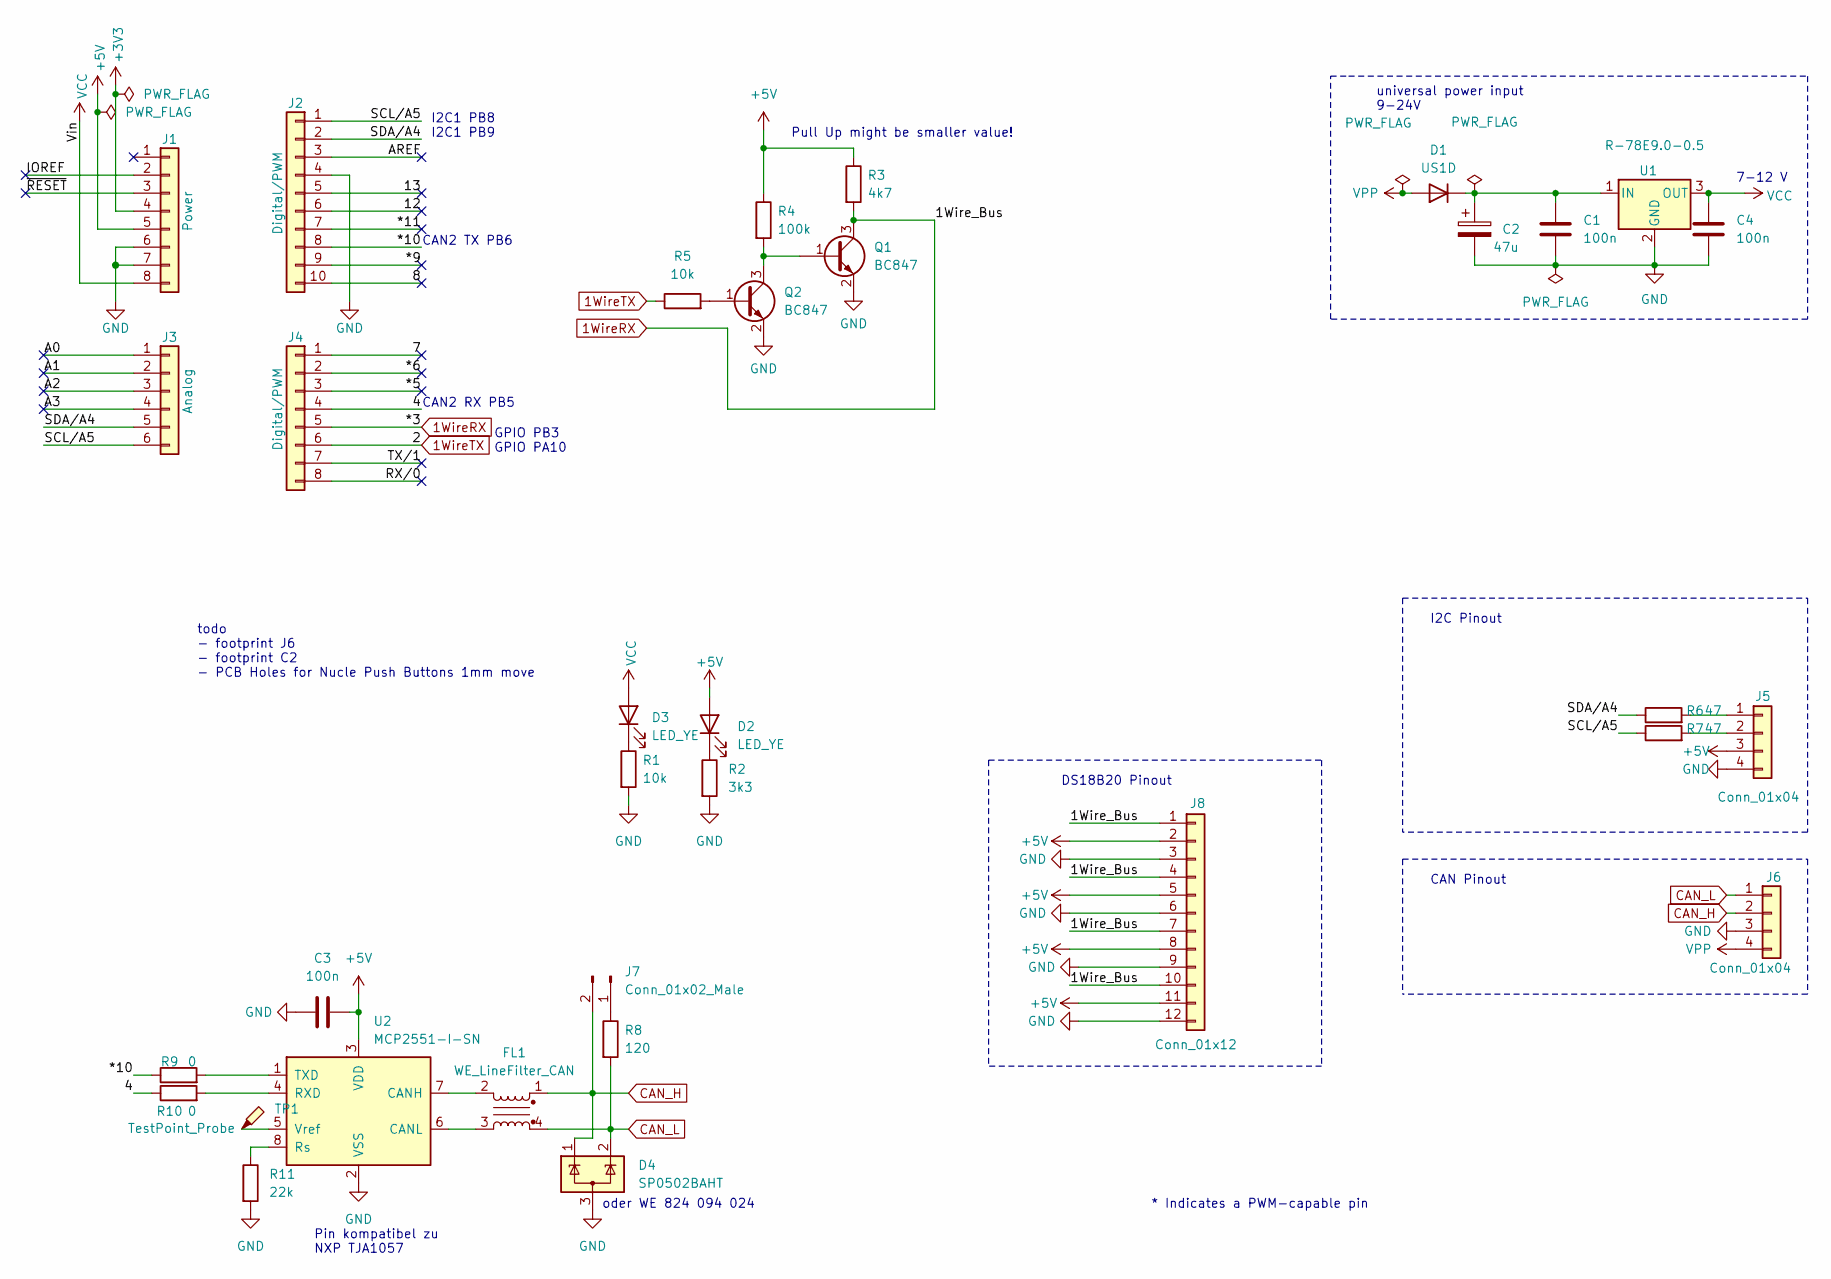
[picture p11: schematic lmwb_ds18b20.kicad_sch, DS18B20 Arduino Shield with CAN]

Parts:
C1, C3, C4: 100n; C_1206_3216Metric_Pad1.33x1.80mm_HandSolder
C2: 47u; CP_Elec_10x12.5
D1: US1D; D_SMA
D2, D3: LED_YE; LED_1210_3225Metric_Pad1.42x2.65mm_HandSolder
D4: SP0502BAHT; SOT-23
FL1: WE_LineFilter_CAN; L_CommonModeChoke_CAN_lmwb
J1: Power; PinSocket_1x08_P2.54mm_Vertical
J2: Digital/PWM; PinSocket_1x10_P2.54mm_Vertical
J3: Analog; PinSocket_1x06_P2.54mm_Vertical
J4: Digital/PWM; PinSocket_1x08_P2.54mm_Vertical
J5: Conn_01x04; PinHeader_1x04_P2.54mm_Vertical
J6: Conn_01x04; TerminalBlock_Phoenix_MPT-0,5-4-2.54_1x04_P2.54mm_Horizontal
J7: Conn_01x02_Male; PinHeader_1x02_P2.54mm_Vertical
J8: Conn_01x12; TerminalBlock_Phoenix_MPT-0,5-12-2.54_1x12_P2.54mm_Horizont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
Q1, Q2: BC847; SOT-23
R1, R5: 10k; R_1206_3216Metric_Pad1.30x1.75mm_HandSolder
R2: 3k3; R_1206_3216Metric_Pad1.30x1.75mm_HandSolder
R3: 4k7; R_1206_3216Metric_Pad1.30x1.75mm_HandSolder
R4: 100k; R_1206_3216Metric_Pad1.30x1.75mm_HandSolder
R6, R7: 47; R_1206_3216Metric_Pad1.30x1.75mm_HandSolder
R8: 120; R_1206_3216Metric_Pad1.30x1.75mm_HandSolder
R9, R10: 0; R_1206_3216Metric_Pad1.30x1.75mm_HandSolder
R11: 22k; R_1206_3216Metric_Pad1.30x1.75mm_HandSolder
TP1: TestPoint_Probe; TestPoint_Pad_1.5x1.5mm
U1: R-78E9.0-0.5; Converter_DCDC_RECOM_R-78E-0.5_THT
U2: MCP2551-I-SN; SOIC-8_3.9x4.9mm_P1.27mm

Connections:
1WireRX: J4.5, J8.1, J8.4, J8.7, J8.10, Q1.3 (C), R3.2
1WireTX: J4.6, R5.1
+3V3: J1.4
+5V: C3.2, D2.2 (A), J1.5, J5.3, J8.2, J8.5, J8.8, J8.11, R3.1, R4.1, U2.3 (VDD)
/4: J4.4, R10.1
/7: J4.1
/8: J2.10
/12: J2.6
/13: J2.5
/*5: J4.3
/*6: J4.2
/*9: J2.9
/*10: J2.8, R9.1
/*11: J2.7
/A0: J3.1
/A1: J3.2
/A2: J3.3
/A3: J3.4
/AREF: J2.3
/IOREF: J1.2
/RX/0: J4.8
/SCL/A5: J2.1, J3.6, R7.1
/SDA/A4: J2.2, J3.5, R6.1
/TX/1: J4.7
/~RESET: J1.3
CAN_H: D4.1 (K), FL1.1, J6.2, J7.2
CAN_L: D4.2 (K), FL1.4, J6.1, R8.2
GND: C1.2, C2.2, C3.1, C4.2, D4.3 (A), J1.6, J1.7, J2.4, J5.4, J6.3, J8.3, J8.6, J8.9, J8.12, Q1.2 (E), Q2.2 (E), R1.2, R2.2, R11.2, U1.2 (GND), U2.2 (VSS)
unnamed: C1.1, C2.1, D1.1 (K), U1.1 (IN)
unnamed: D2.1 (K), R2.1
unnamed: D3.1 (K), R1.1
unnamed: FL1.2, U2.7 (CANH)
unnamed: FL1.3, U2.6 (CANL)
unnamed: J5.1, R6.2
unnamed: J5.2, R7.2
unnamed: J7.1, R8.1
unnamed: Q1.1 (B), Q2.3 (C), R4.2
unnamed: Q2.1 (B), R5.2
unnamed: R9.2, U2.1 (TXD)
unnamed: R10.2, U2.4 (RXD)
unnamed: R11.1, U2.8 (Rs)
unnamed: TP1.1, U2.5 (Vref)
VCC: C4.1, D3.2 (A), J1.8, U1.3 (OUT)
VPP: D1.2 (A), J6.4

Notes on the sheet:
Pin kompatibel zu NXP TJA1057
I2C1 PB8 I2C1 PB9
7-12 V
CAN Pinout
CAN2 RX PB5
Pull Up might be smaller value!
GPIO PB3 GPIO PA10
CAN2 TX PB6
todo - footprint J6 - footprint C2 - PCB Holes for Nucle Push Buttons 1mm move
I2C Pinout
oder WE 824 094 024
* Indicates a PWM-capable pin
DS18B20 Pinout
universal power input 9-24V

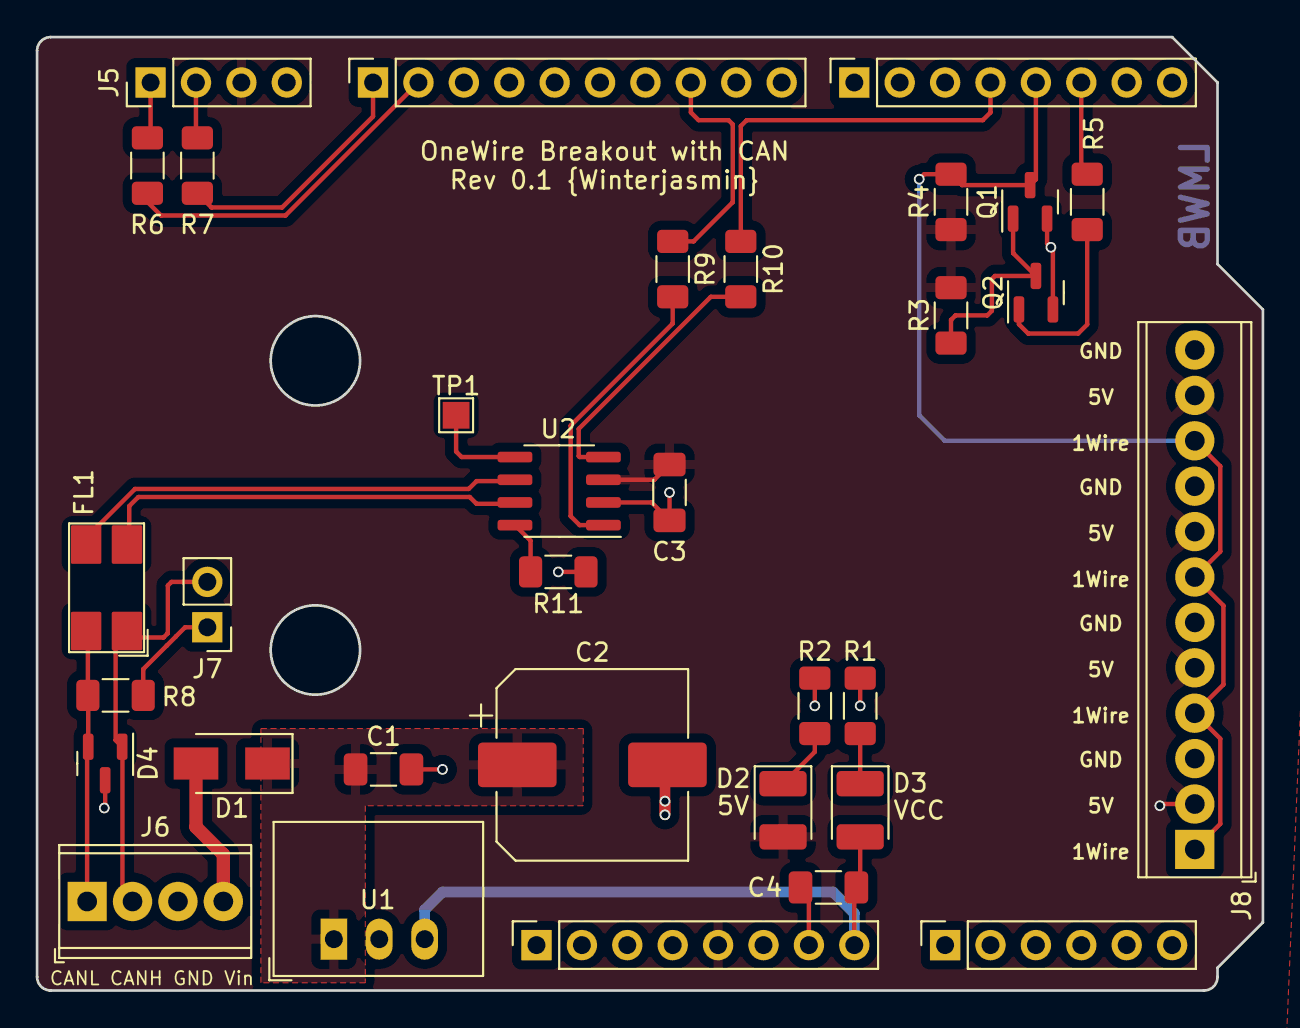
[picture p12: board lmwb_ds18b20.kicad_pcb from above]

Board: 2 copper layers, 68.6 x 53.3 mm, 33 parts (0 on the bottom side), 26 nets.

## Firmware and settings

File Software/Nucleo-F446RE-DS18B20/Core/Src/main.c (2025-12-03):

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
/* Includes ------------------------------------------------------------------*/
#include "main.h"
#include "can.h"
#include "i2c.h"
#include "tim.h"
#include "usart.h"
#include "gpio.h"

/* USER CODE BEGIN Includes */
#include "ds18b20.h"
#include "app_can.h"
/* USER CODE END Includes */


void SystemClock_Config(void);
/* USER CODE BEGIN 0 */
uint32_t tickNow = 0;
uint32_t tick = 0;
/* USER CODE END 0 */

/**
 * @brief  The application entry point.
 * @retval int
 */
int main(void) {

	/* MCU Configuration--------------------------------------------------------*/

	/* Reset of all peripherals, Initializes the Flash interface and the Systick. */
	HAL_Init();

	/* Configure the system clock */
	SystemClock_Config();

	/* Initialize all configured peripherals */
	MX_GPIO_Init();
	MX_USART2_UART_Init();
	MX_TIM6_Init();
	MX_CAN2_Init();
	MX_I2C1_Init();
	MX_TIM7_Init();
	/* USER CODE BEGIN 2 */

	/* CAN Stuff */
	app_can_set_msg_filter();

	app_can_start();

	HAL_Delay(100);
	if (app_can_send_test_msg() != 0) {
		my_printf("Sending Test CAN Msg Failed\n");
	}
	/* CAN Stuff End */

	/* USER CODE END 2 */

	/* Infinite loop */
	/* USER CODE BEGIN WHILE */

	app_can_send_test_msg();

	HAL_TIM_Base_Start_IT(&htim7);

	HAL_Delay(300);

	my_printf("DS18B20 One Wire Temperature Sensor Demo\n");
	my_printf("\nStart 1-Wire Search Algorithm ... \n");
	uint8_t n = ds18b20_scan_for_devices_on_bus();
	my_printf("\nSummary: Found %d DS18B20 Sensors on the 1-Wire Bus\n", n);

	for (uint8_t i = 0; i < n; i++) {
		DS18B20_t ds18b20;
		if (ds18b20_get_devices_serial_number(i, &ds18b20)) {
			my_printf("..Found Device with SerNo: %d %d %d %d %d %d %d %d\n",
					ds18b20.familycode, ds18b20.ID[0], ds18b20.ID[1],
					ds18b20.ID[2], ds18b20.ID[3], ds18b20.ID[4], ds18b20.ID[5],
					ds18b20.CRC_Byte);
		}
	}

	my_printf("Start Continuously Reading of DS18B20 Sensors on the 1-Wire Bus\n\n");
	ds18b20_send_start_conversion_to_all_devices();
	while (1) {
		/* USER CODE END WHILE */

		/* USER CODE BEGIN 3 */
		static int32_t t1;
		static int32_t t2;
		static int32_t t3;
		static int32_t t4;
		tickNow = HAL_GetTick();

		if (ds18b20_check_conversion_finished()) {
			ds18b20_read_temperature_from_scratchpad(0, &t1);
			ds18b20_read_temperature_from_scratchpad(1, &t2);
			ds18b20_read_temperature_from_scratchpad(2, &t3);
			ds18b20_read_temperature_from_scratchpad(3, &t4);
			ds18b20_send_start_conversion_to_all_devices();
		}

		// quick and dirty timing scheduler for out put results to record on serial terminal
		if ((tickNow - tick) >= 5000) {
			tick = tickNow;

			float f1,f2,f3,f4;
			f1 = t1/1000.0;
			f2 = t2/1000.0;
			f3 = t3/1000.0;
			f4 = t4/1000.0;
			my_printf("{"
					"\"T1\": %2.2f,"
					"\"T2\": %2.2f,"
					"\"T3\": %2.2f,"
					"\"T4\": %2.2f}\r\n", f1, f2, f3, f4);
		}

		/* two ore more 1Wire-Device on the bus! */
		//ds18b20_demo_multi();
		/* one single 1Wire-Device on the bus only! */
		//ds18b20_demo();
	}
	/* USER CODE END 3 */
}

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
/* USER CODE BEGIN 4 */

void HAL_CAN_RxFifo0FullCallback(CAN_HandleTypeDef *hcan) {
	my_printf(" CAN fifo full \n");
}

void HAL_CAN_ErrorCallback(CAN_HandleTypeDef *hcan) {
	uint32_t error = hcan->ErrorCode; /*!< This parameter can be a value of @ref CAN_Error_Code */

	my_printf("CAN Error %d\n", error);

}

void HAL_CAN_RxFifo0MsgPendingCallback(CAN_HandleTypeDef *hcan) {
	CAN_RxHeaderTypeDef sRxHeader;
	HAL_StatusTypeDef TX_RX_status;
	uint32_t fifoFillLevel;
	uint8_t RxData[8];
	uint8_t canHW = 0;
	uint32_t canID = 0;

	if (hcan->Instance == CAN2) {
		fifoFillLevel = HAL_CAN_GetRxFifoFillLevel(&hcan2, CAN_RX_FIFO0);
		TX_RX_status = HAL_CAN_GetRxMessage(&hcan2, CAN_RX_FIFO0, &sRxHeader,
				RxData);
		canHW = 2;
	}

	if ( CAN_ID_STD == sRxHeader.IDE) {
		canID = sRxHeader.StdId;
	}

	if ( CAN_ID_EXT == sRxHeader.IDE) {
		canID = sRxHeader.ExtId;
	}

	char buf[128];
	uint16_t s = 0;
	s = sprintf(buf,
			"Rec from CAN %d with ID 0x%lX Msg: %d %d %d %d %d %d %d %d\n",
			canHW, canID, RxData[0], RxData[1], RxData[2], RxData[3], RxData[4],
			RxData[5], RxData[6], RxData[7]);
	HAL_UART_Transmit(&huart2, (uint8_t*) buf, s, 100);

}

void HAL_TIM_PeriodElapsedCallback(TIM_HandleTypeDef *htim) {

	if (htim->Instance == TIM7) {
		app_can_send_test_msg();
	}
}

/* USER CODE END 4 */
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


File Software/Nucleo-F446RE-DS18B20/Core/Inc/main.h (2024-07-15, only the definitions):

#define B1_Pin GPIO_PIN_13
#define B1_GPIO_Port GPIOC
#define USART_TX_Pin GPIO_PIN_2
#define USART_TX_GPIO_Port GPIOA
#define USART_RX_Pin GPIO_PIN_3
#define USART_RX_GPIO_Port GPIOA
#define LD2_Pin GPIO_PIN_5
#define LD2_GPIO_Port GPIOA
#define OneWireTX_Pin GPIO_PIN_10
#define OneWireTX_GPIO_Port GPIOA
#define TMS_Pin GPIO_PIN_13
#define TMS_GPIO_Port GPIOA
#define TCK_Pin GPIO_PIN_14
#define TCK_GPIO_Port GPIOA
#define OneWireTX_alt_Pin GPIO_PIN_10
#define OneWireTX_alt_GPIO_Port GPIOC
#define OneWireRX_alt_Pin GPIO_PIN_11
#define OneWireRX_alt_GPIO_Port GPIOC
#define OneWireRX_Pin GPIO_PIN_3
#define OneWireRX_GPIO_Port GPIOB

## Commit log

2024-07-15 add software, hardware, datasheet resorces
    [BOM_lmwb_ds18b20.csv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]
2024-07-18 added schematics
2024-09-21 added getter for serial-number of one wire diveces present on the bus
2024-09-23 added test results
    [ds18b20-log.csv, pt1000-log.csv]
2025-04-14 Output string format to csv (#1)
    * added format csv compatible output string
    * added getter for serial-number of one wire diveces present on the bus
    * reshape main-loop
    * added test results
    ---------
    [ds18b20-log.csv, pt1000-log.csv]
2025-12-02 Output string format to csv (#1) (#2) (#3)
    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

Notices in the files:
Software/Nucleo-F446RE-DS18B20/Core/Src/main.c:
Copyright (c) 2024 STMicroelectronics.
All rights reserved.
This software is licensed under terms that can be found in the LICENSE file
